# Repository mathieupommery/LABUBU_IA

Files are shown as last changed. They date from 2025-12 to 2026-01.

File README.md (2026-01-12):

# LABUBU IA

<p align="center">
  
</p>

## Hardware

###  Specs
- ESP32-S3
- MEMS Micro ICS-43434
- Amplifier Max 98357
- Built-in LTC4065 lipo charger 
- Built-in 1s lipo and micro sd card
- WIFI/BLE antenna connector
- Push button for application purpose
- connector for external on/off switch, external USB, external speaker and adressable led.

###  PCB
- 4 layers under 900mm2

### Some view 

<p align="center">
  
  
</p>

### 3D pcb case 
<p align="center">
  
  
</p>

##  Software

### Audio_Player 
- Scan button at startup: if pressed goes into msc mode and expose sd card on usb to add new song (sd in spi mode too extremely slow)
- After that scan all the .wav in the memory
- then if you short press : toggle the play state of the current song
- if you long press : play the next song in alphabetical order.

### IA_assistant

-in progress 

## Result 

Picture of the pcb ( cable on top are soldered because i had not the jst ghs 8pin in stock )

<p align="center">
  
  
</p>

View of the pcb with the 1s 150mah lipo battery connected
<p align="center">
  
</p>

View of the External power switch (on one side battery is disconnected from ldo and usb is connected to ldo and on other side usb is disconnected from ldo and battery is connected ) 
and view of the usb port both are hidden in the labubu's feet.

<p align="center">
  
  
</p>

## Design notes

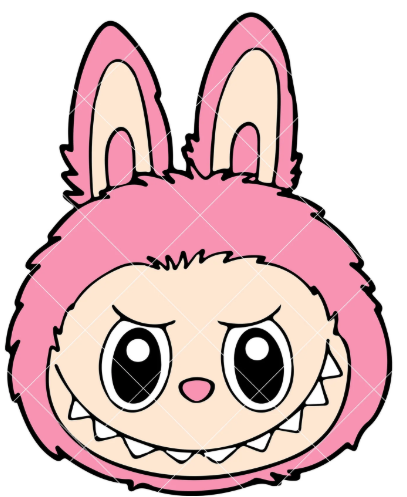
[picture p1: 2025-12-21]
DOCS/labubu.png

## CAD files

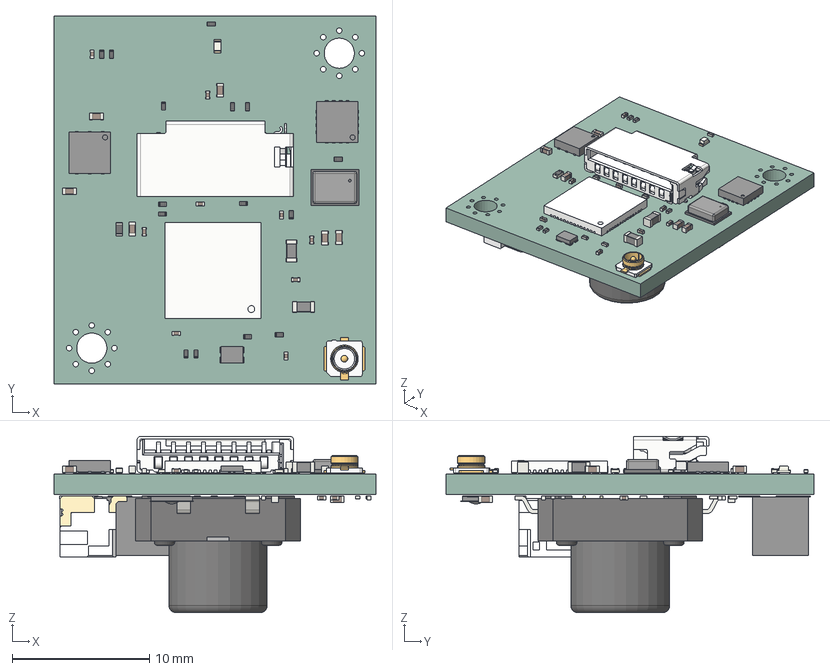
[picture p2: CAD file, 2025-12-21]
HARDWARE/3D/labubupcb.step
23.4 x 26.8 x 12.8 mm
R_0201_0603Metric x 20
C_0402_1005Metric x 9
C_0201_0603Metric x 13
L_0603_1608Metric x 2
ThermalPin
PinsArrayLR
PinsArrayTB
R_0402_1005Metric
LED_0402_1005Metric
Pins
InvenSense_ICS-43434-6_3.5x2.65mm
636101112001_Contact
636101112001_Ground
636101112001_Housing
ThermalPin_1
PinsArrayLR_1
labubupcb 1.41.1
ThermalPin_2
PinsArrayLR_2
SM04B-GHS-TB_LF__SN_
KXT341LHS
SW_Push_1P1T_NO_CK_PTS125Sx85SMTR
Pins_1
PCB_PAPI_PCB

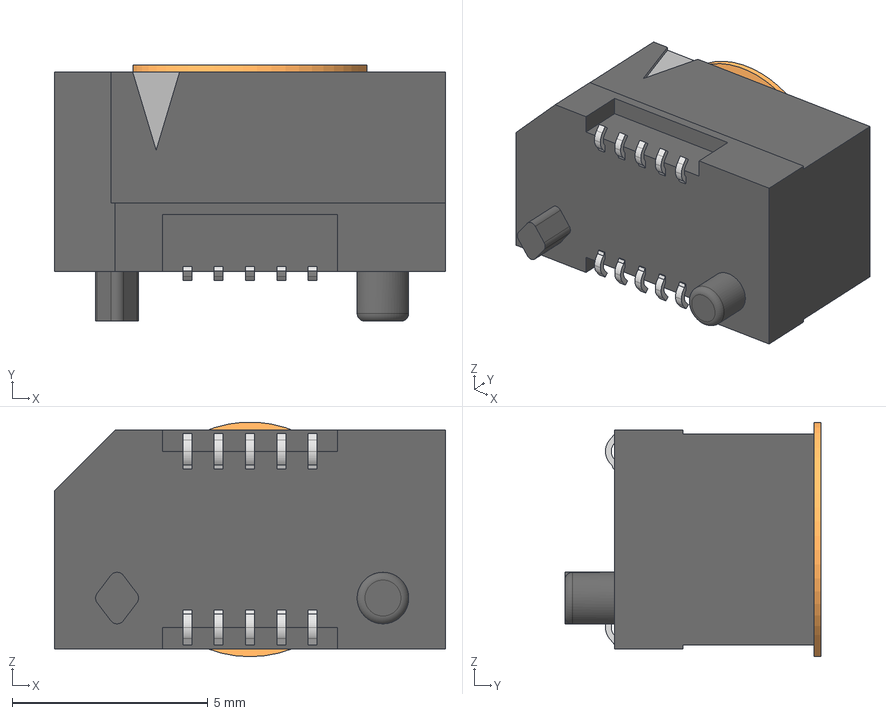
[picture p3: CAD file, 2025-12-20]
HARDWARE/PCB/LIB_KIKAD/ERF8-005/ERF8-005-05.0-L-DV-K-TR.stp
10.0 x 6.56 x 5.99 mm
ERF8-005-05.0-DV-KTR
ERF8-C-211-05.0-005PN
ERF8-C-211-05.0-0052PN
ERF8-005-05.0-DVPFP

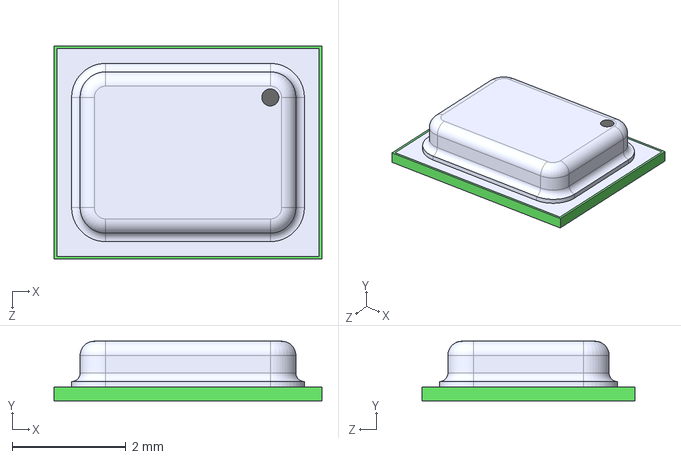
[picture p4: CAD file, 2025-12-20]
HARDWARE/PCB/LIB_KIKAD/INMP441/INMP441ACEZ-R7.step
4.72 x 1.05 x 3.76 mm

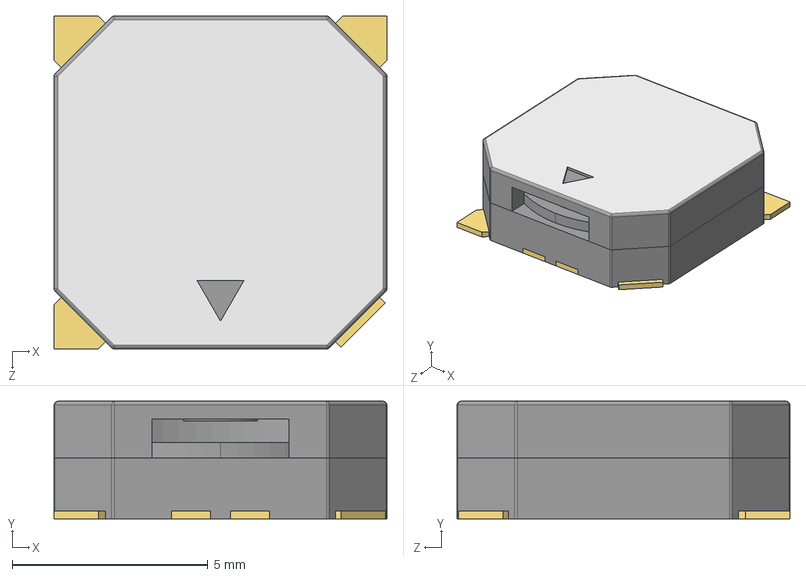
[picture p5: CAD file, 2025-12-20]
HARDWARE/PCB/LIB_KIKAD/libloader/CMT-8503-90-SMT-TR.stp
8.50 x 3.00 x 8.50 mm

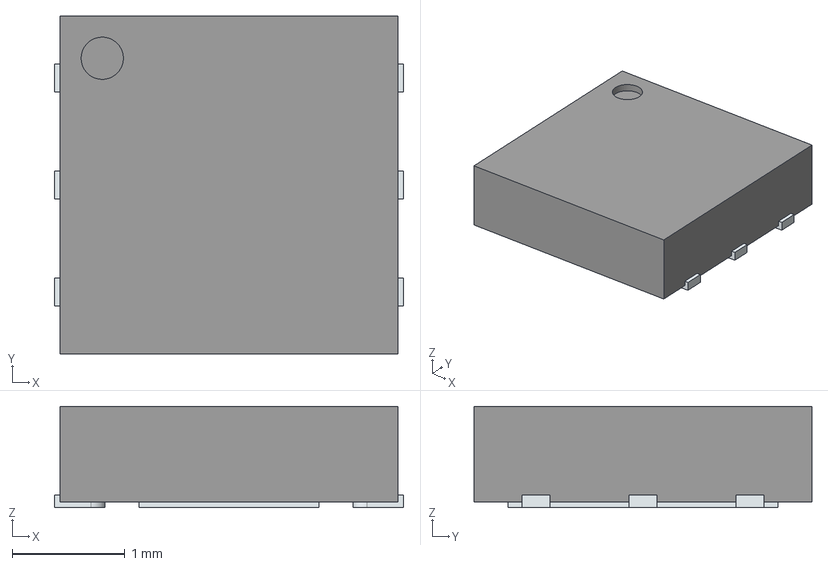
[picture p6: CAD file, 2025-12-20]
HARDWARE/PCB/LIB_KIKAD/libloader/LDO40LPU33RY.stp
3.10 x 3.00 x 0.9 mm
ThermalPin
PinsArrayLR

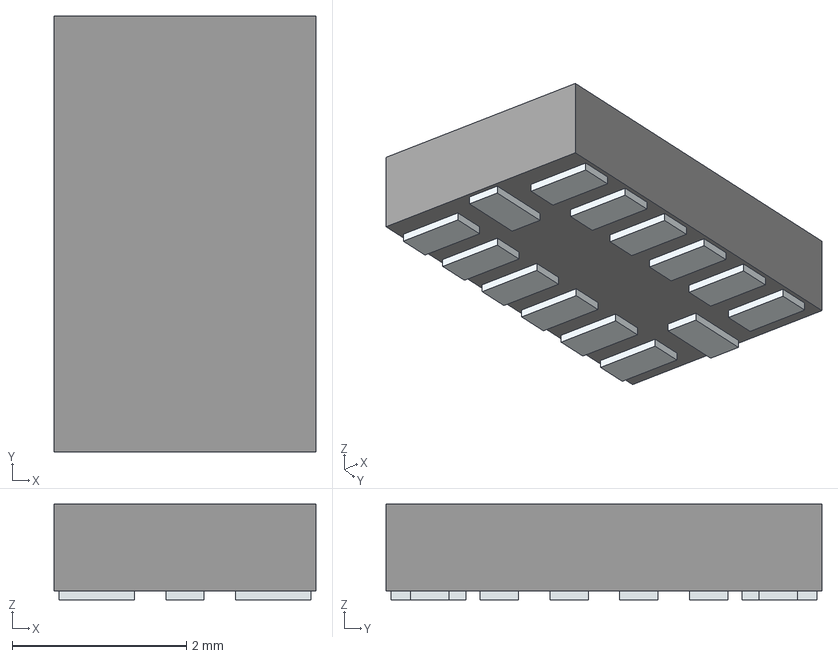
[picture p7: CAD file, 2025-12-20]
HARDWARE/PCB/LIB_KIKAD/libloader/ADXL343BCCZ-RL.stp
3.00 x 5.00 x 1.10 mm
Pins

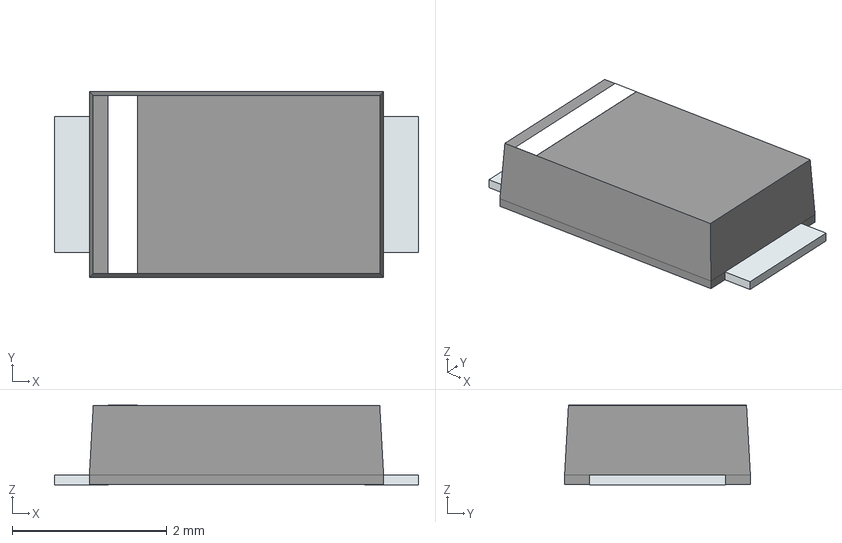
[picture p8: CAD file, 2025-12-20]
HARDWARE/PCB/LIB_KIKAD/libloader/STPS5H100AF.stp
4.70 x 2.40 x 1.03 mm
PinKIdent
PinK
PinA

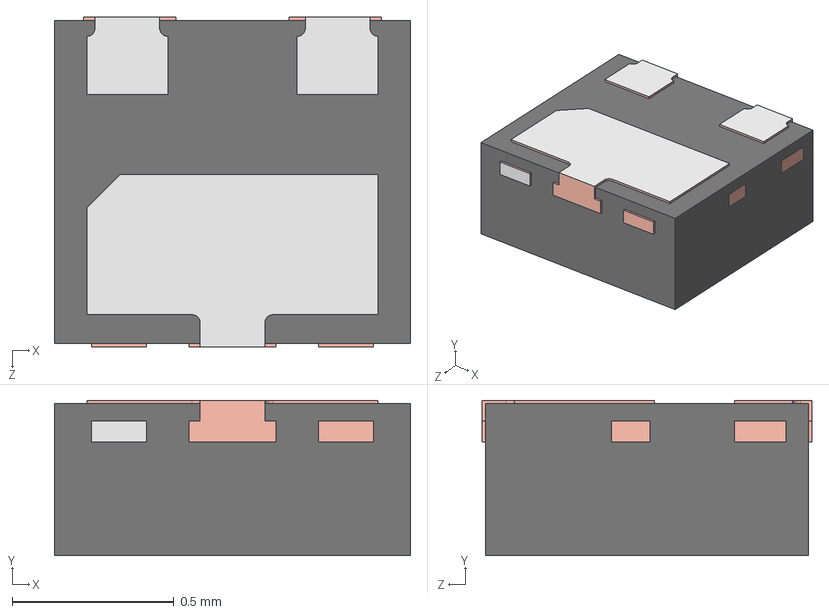
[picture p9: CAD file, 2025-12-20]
HARDWARE/PCB/LIB_KIKAD/libloader/2N7002KQBZ.stp
1.10 x 0.48 x 1.02 mm
SOT8015 LF
SOT8015 Body

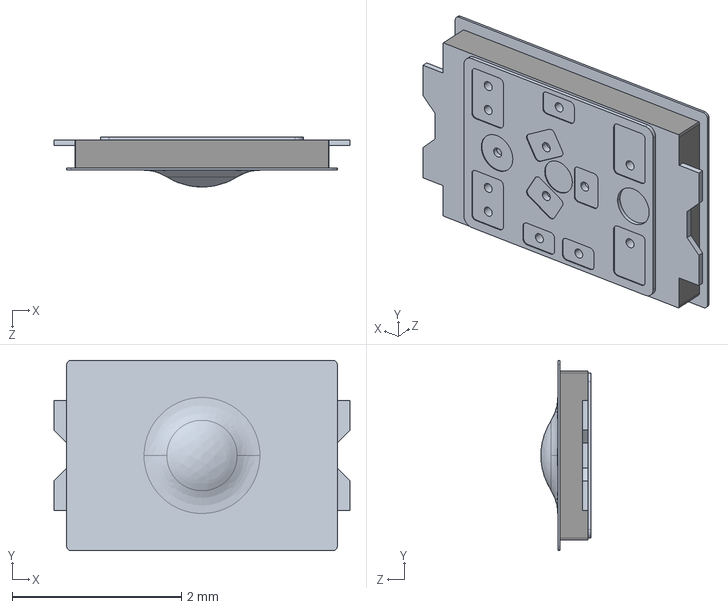
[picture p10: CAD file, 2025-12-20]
HARDWARE/PCB/LIB_KIKAD/libloader/KXT341LHS.stp
3.50 x 2.25 x 0.595 mm

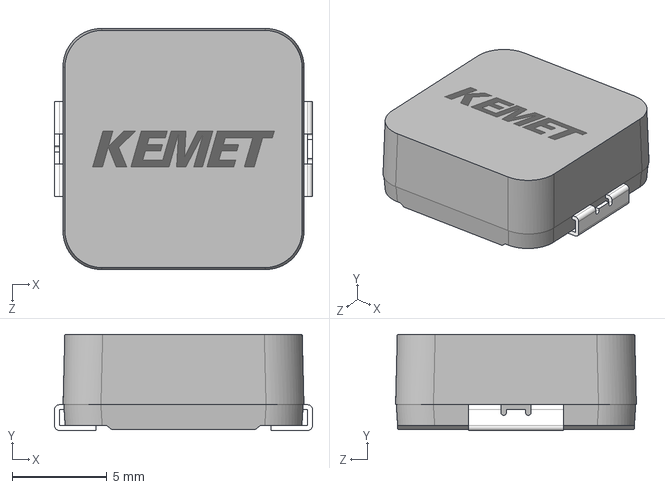
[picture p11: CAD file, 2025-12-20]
HARDWARE/PCB/LIB_KIKAD/libloader/MPX1D1250L4R7.stp
13.6 x 5.06 x 12.7 mm

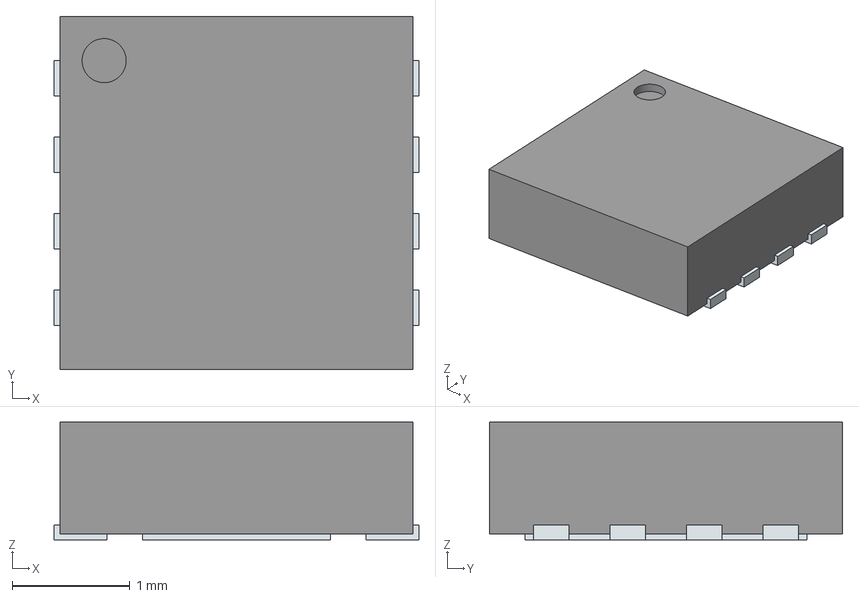
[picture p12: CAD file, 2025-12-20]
HARDWARE/PCB/LIB_KIKAD/libloader/NCV7342MW3R2G.stp
3.10 x 3.00 x 1.00 mm
ThermalPin
PinsArrayLR

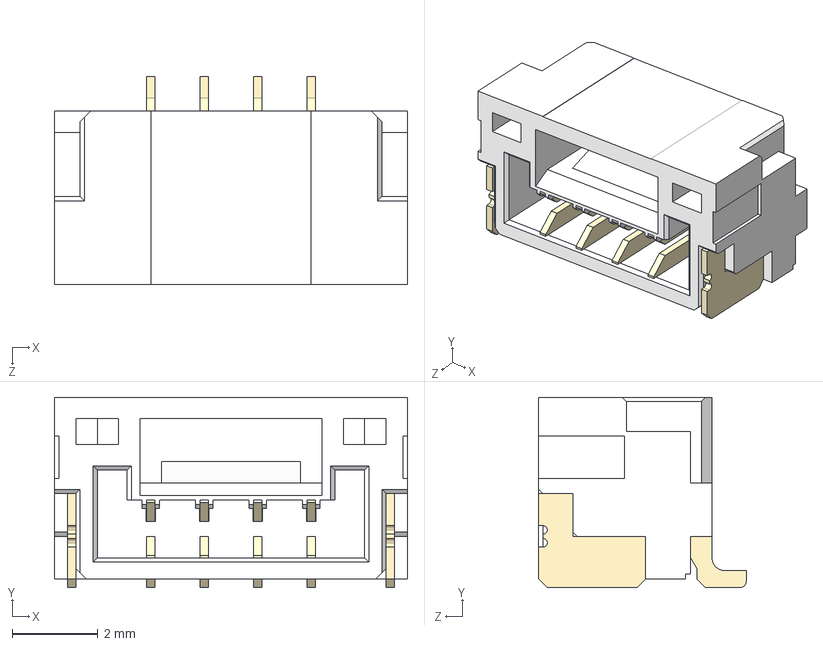
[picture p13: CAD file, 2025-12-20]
HARDWARE/PCB/LIB_KIKAD/libloader/SM04B-GHS-TB_LF__SN_.stp
8.25 x 4.45 x 4.85 mm

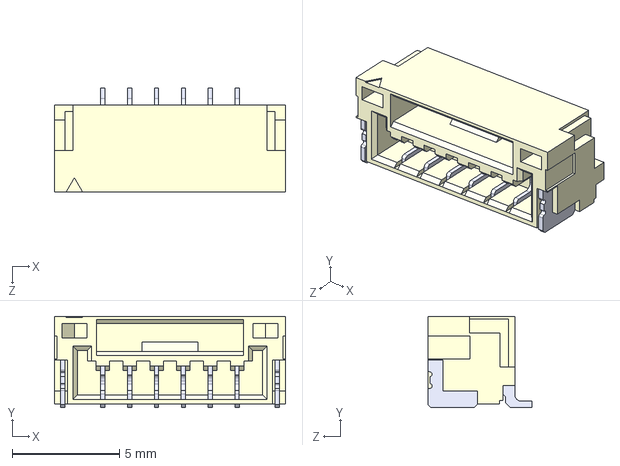
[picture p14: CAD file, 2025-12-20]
HARDWARE/PCB/LIB_KIKAD/libloader/SM06B-GHS-TB_LF__SN_.stp
10.8 x 4.25 x 4.85 mm

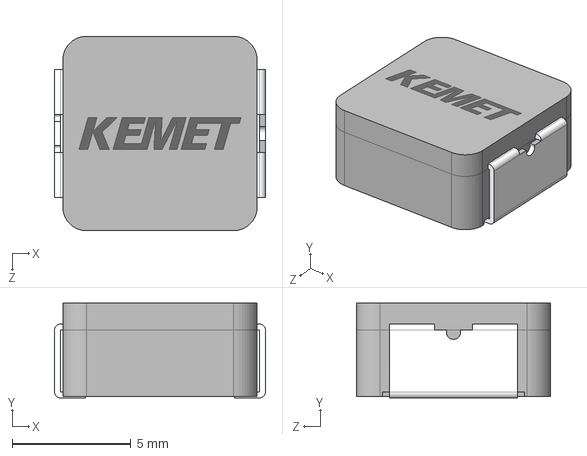
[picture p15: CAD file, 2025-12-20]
HARDWARE/PCB/LIB_KIKAD/libloader/MPX1D0840L470.stp
8.90 x 4.00 x 8.20 mm

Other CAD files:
HARDWARE/PCB/LIB_KIKAD/libloader/SM10B-SRSS-TB_LF__SN_.stp
HARDWARE/PCB/LIB_KIKAD/libloader/TLE5012BE3005XUMA1.stp
HARDWARE/PCB/LIB_KIKAD/libloader/ESP32-S3FH4R2.stp
HARDWARE/PCB/LIB_KIKAD/libloader/XT30PW-M.stp
HARDWARE/PCB/LIB_KIKAD/libloader/1050281001.stp
HARDWARE/PCB/LIB_KIKAD/libloader/3670108.stp
HARDWARE/PCB/LIB_KIKAD/libloader/3670148.stp
HARDWARE/PCB/LIB_KIKAD/libloader/435151014824.stp
HARDWARE/PCB/LIB_KIKAD/libloader/47309-2651.stp
HARDWARE/PCB/LIB_KIKAD/libloader/5871024147F.stp
HARDWARE/PCB/LIB_KIKAD/libloader/636101111001.stp
HARDWARE/PCB/LIB_KIKAD/libloader/687108183722.stp
HARDWARE/PCB/LIB_KIKAD/libloader/7443320470.stp
HARDWARE/PCB/LIB_KIKAD/libloader/74438335033.stp
HARDWARE/PCB/LIB_KIKAD/libloader/74438335220.stp
HARDWARE/PCB/LIB_KIKAD/libloader/74438357100.stp
HARDWARE/PCB/LIB_KIKAD/libloader/74439358100.stp
HARDWARE/PCB/LIB_KIKAD/libloader/82400274.stp
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

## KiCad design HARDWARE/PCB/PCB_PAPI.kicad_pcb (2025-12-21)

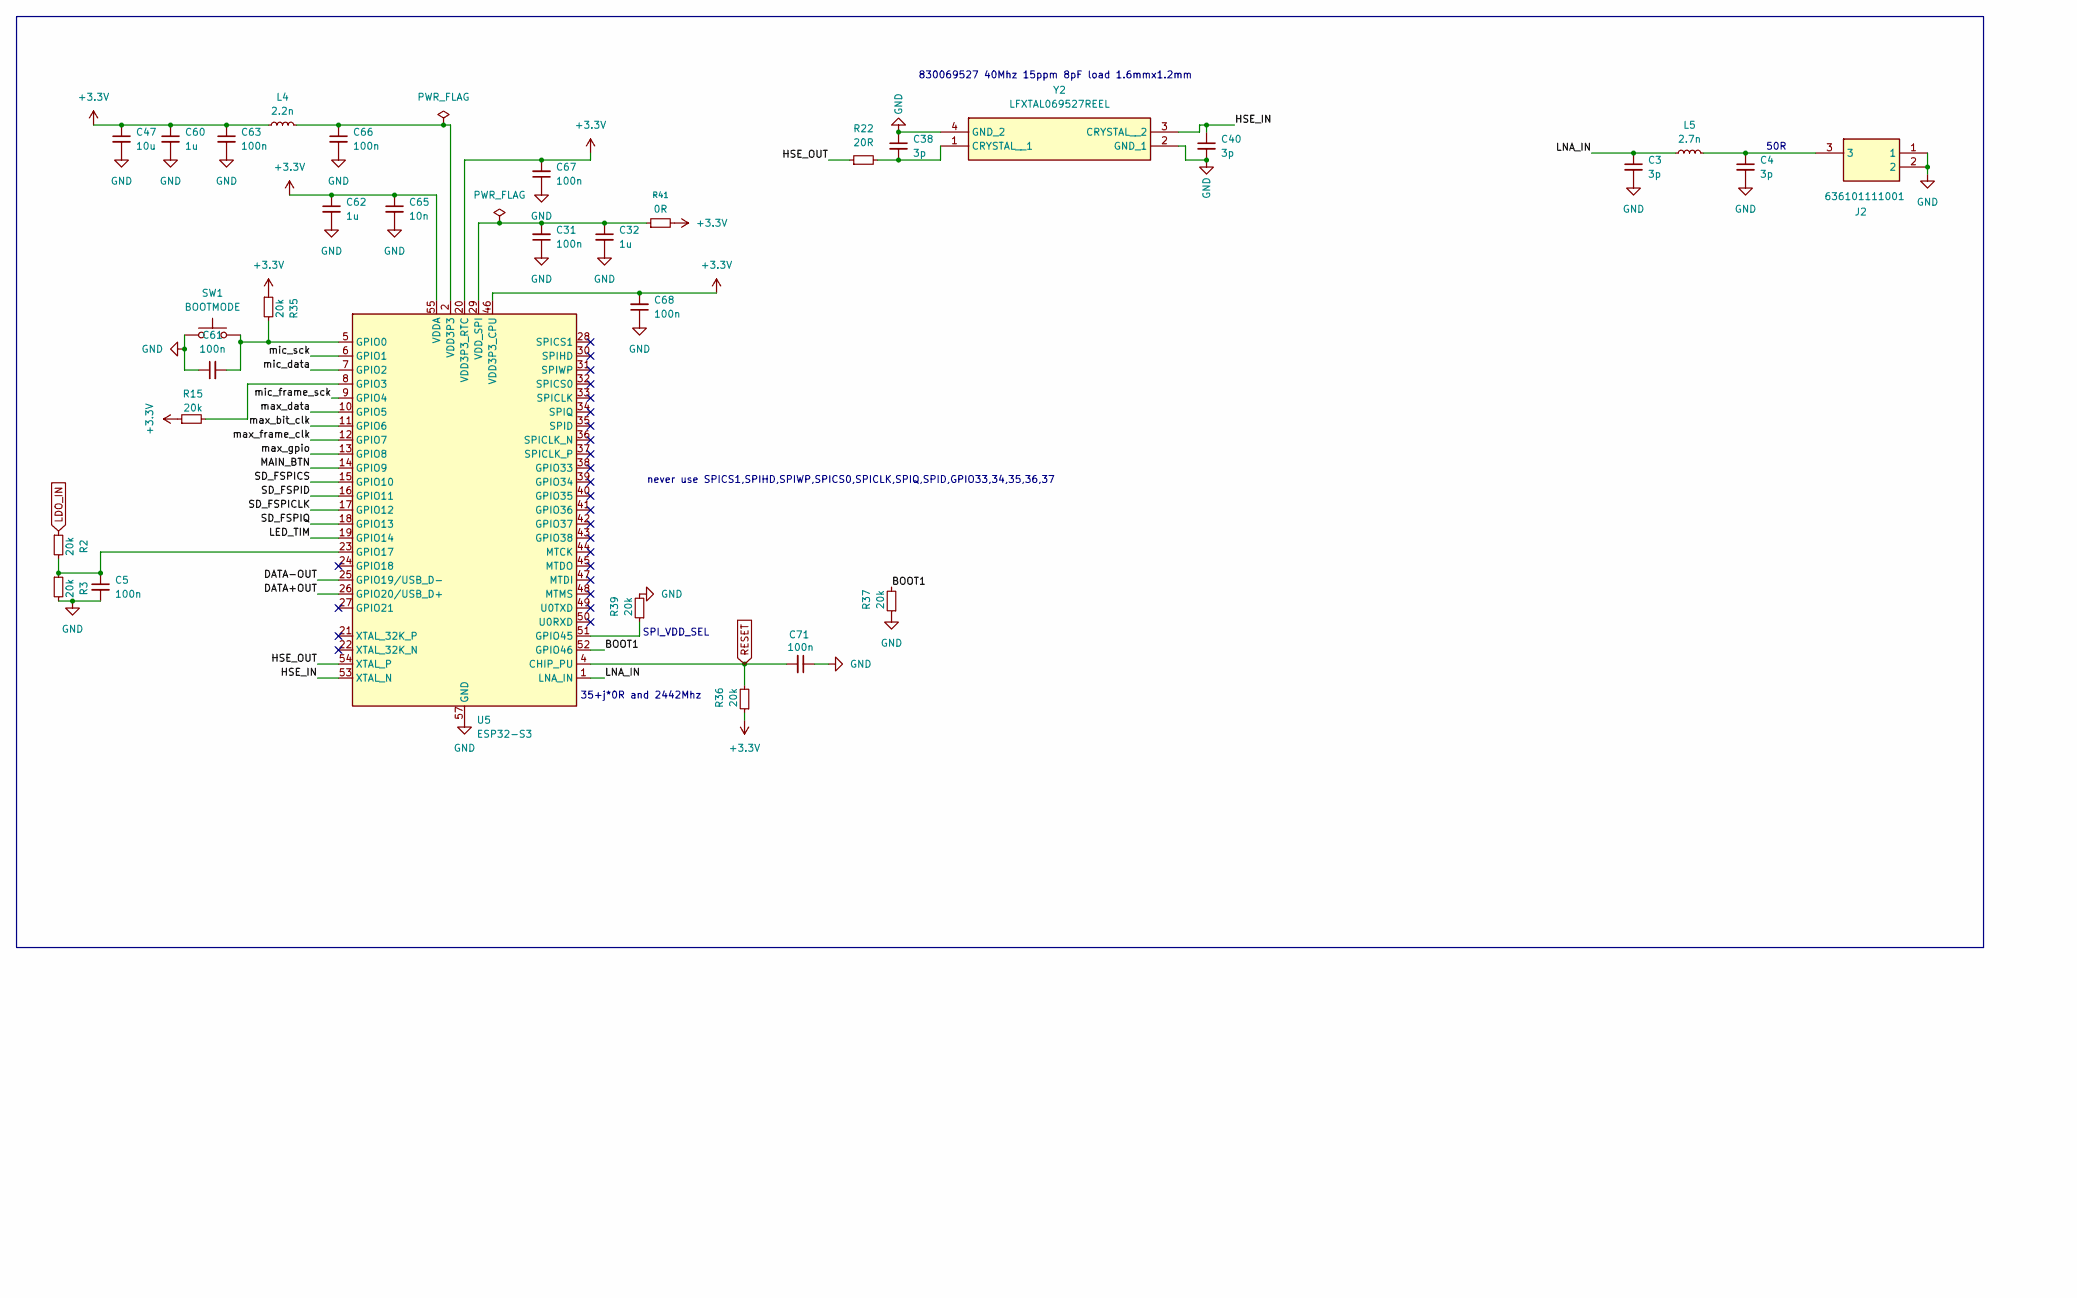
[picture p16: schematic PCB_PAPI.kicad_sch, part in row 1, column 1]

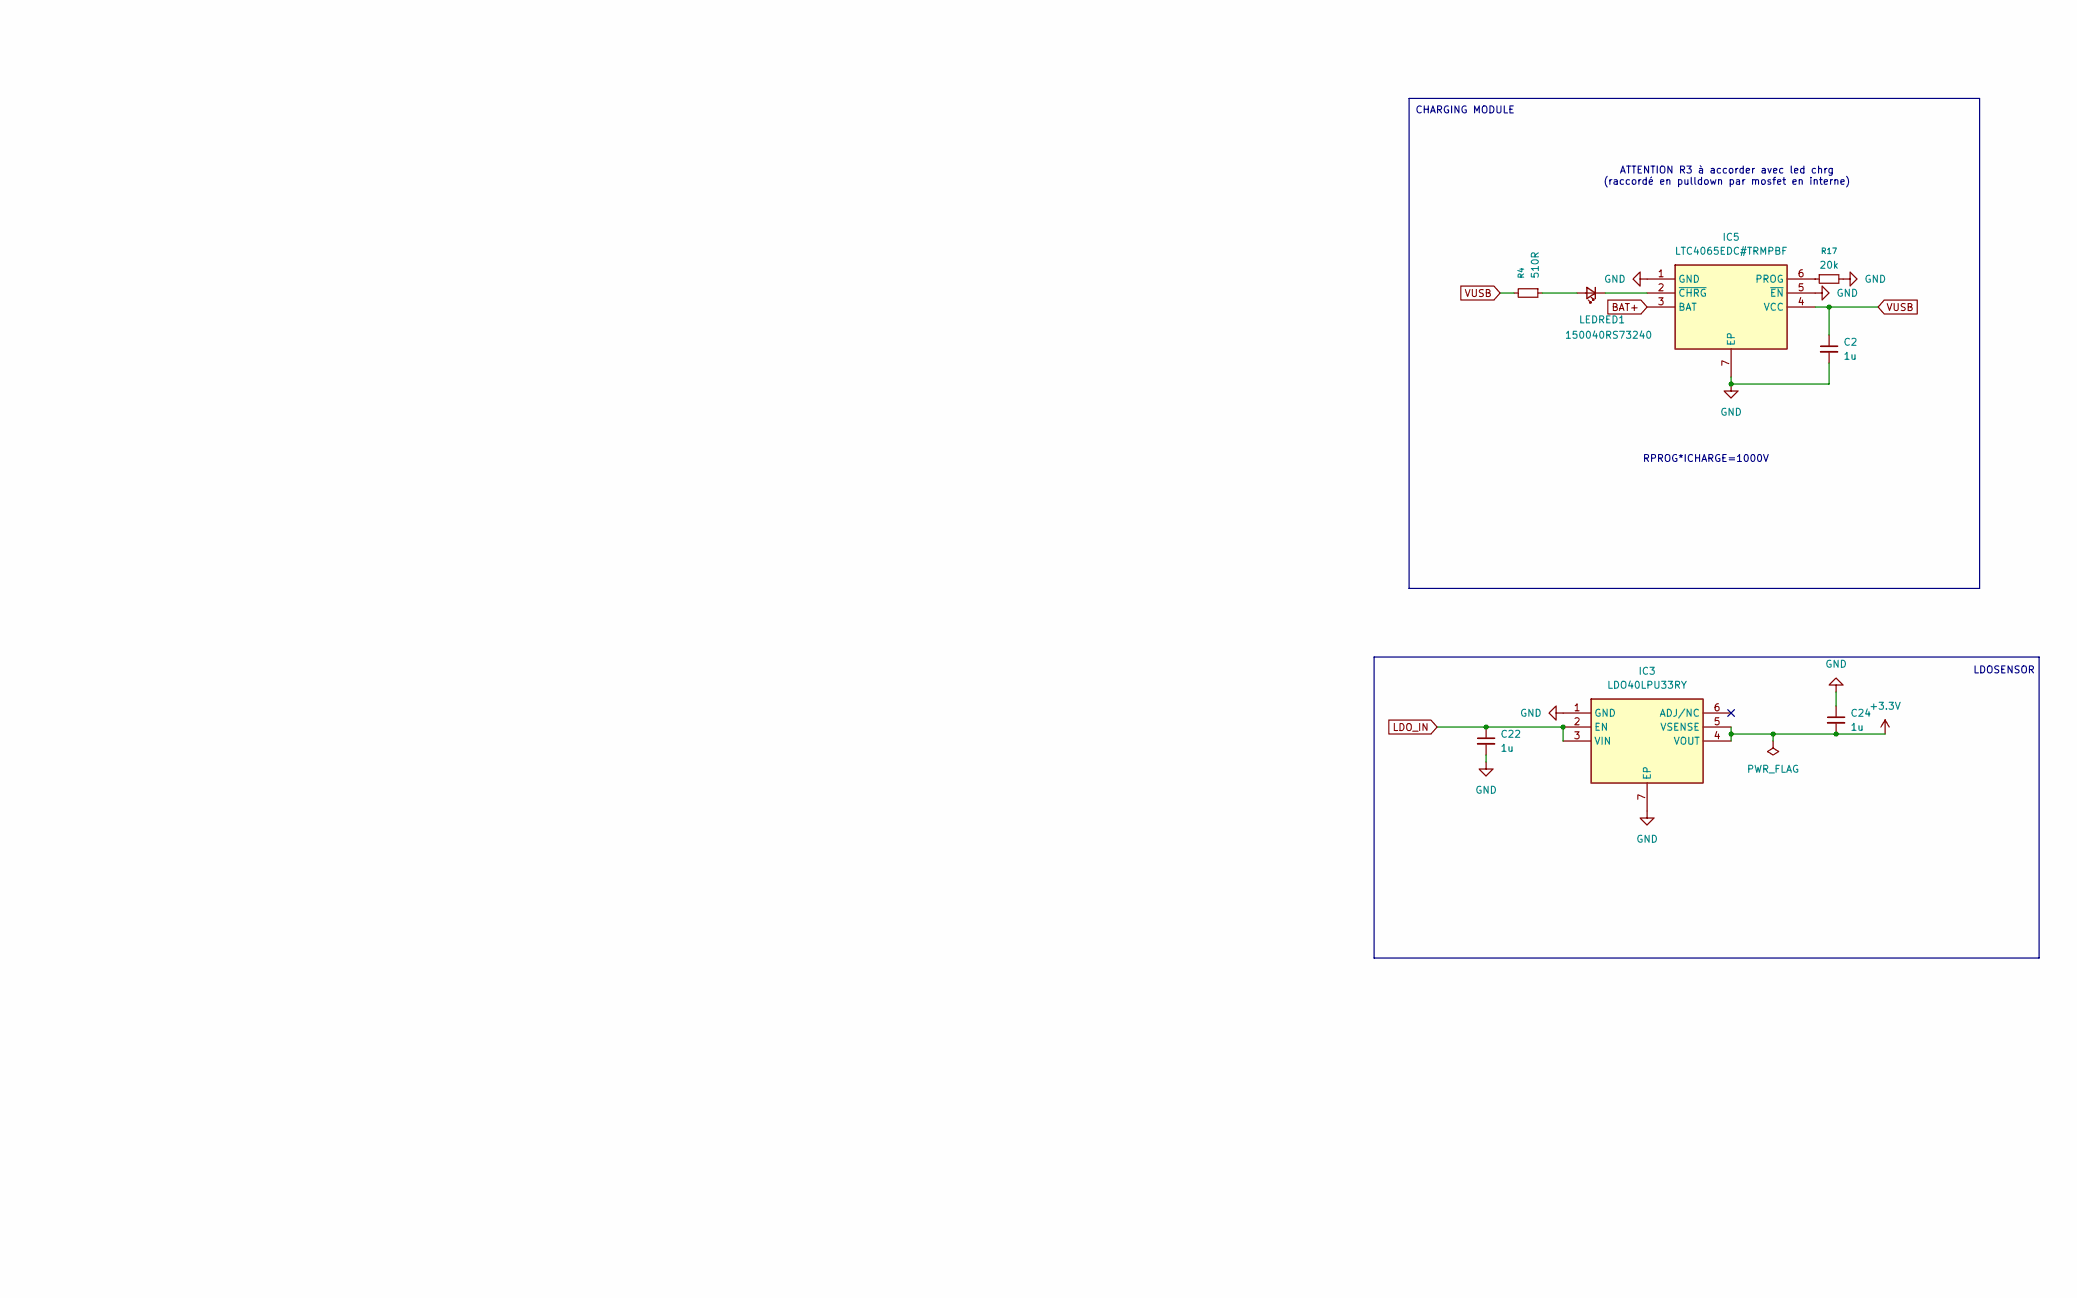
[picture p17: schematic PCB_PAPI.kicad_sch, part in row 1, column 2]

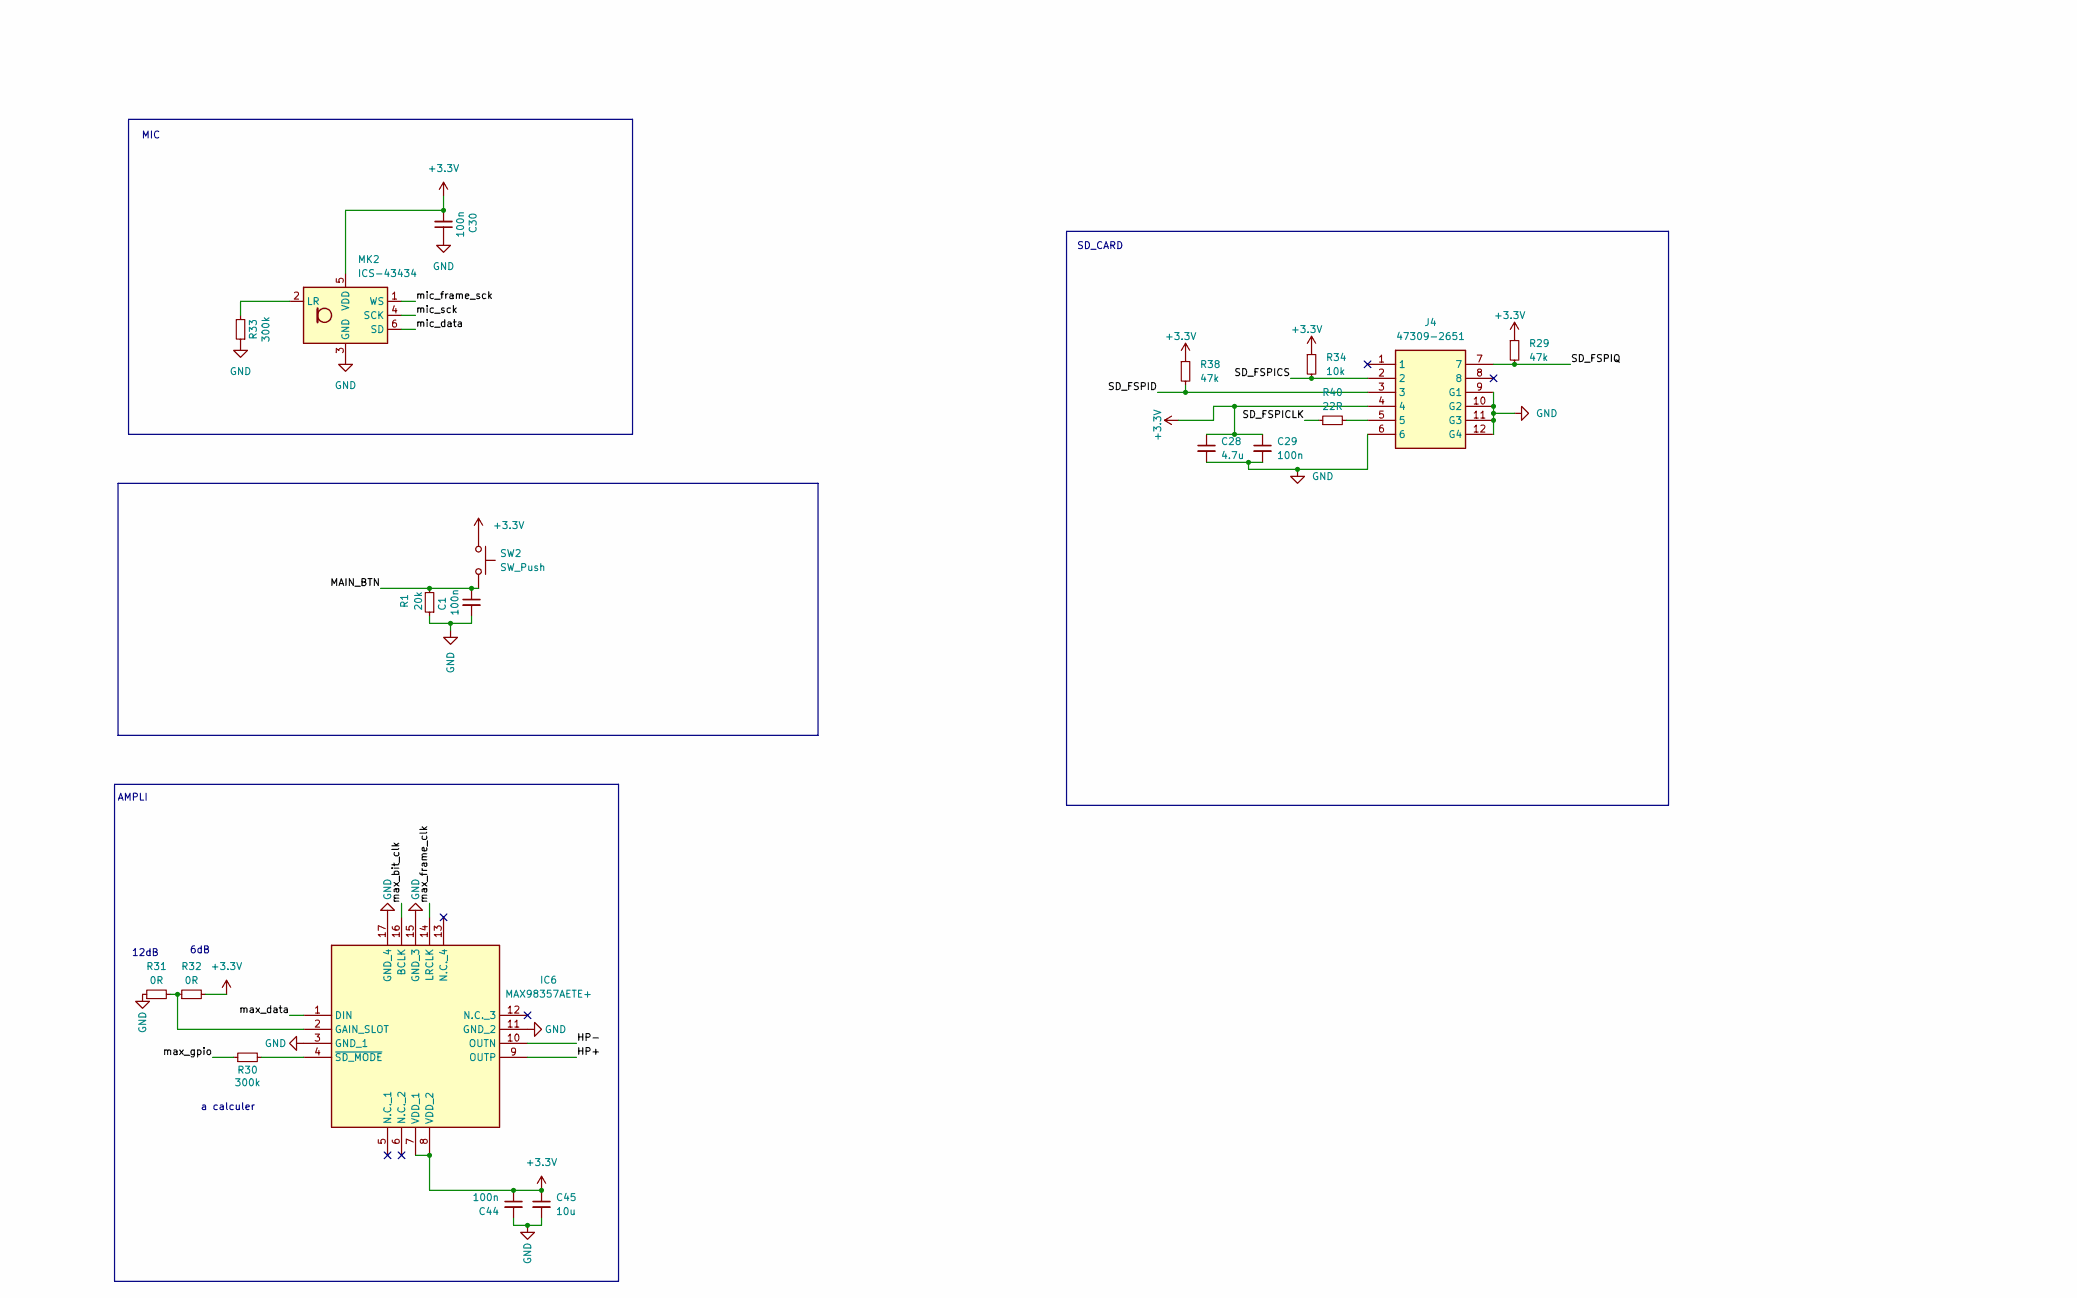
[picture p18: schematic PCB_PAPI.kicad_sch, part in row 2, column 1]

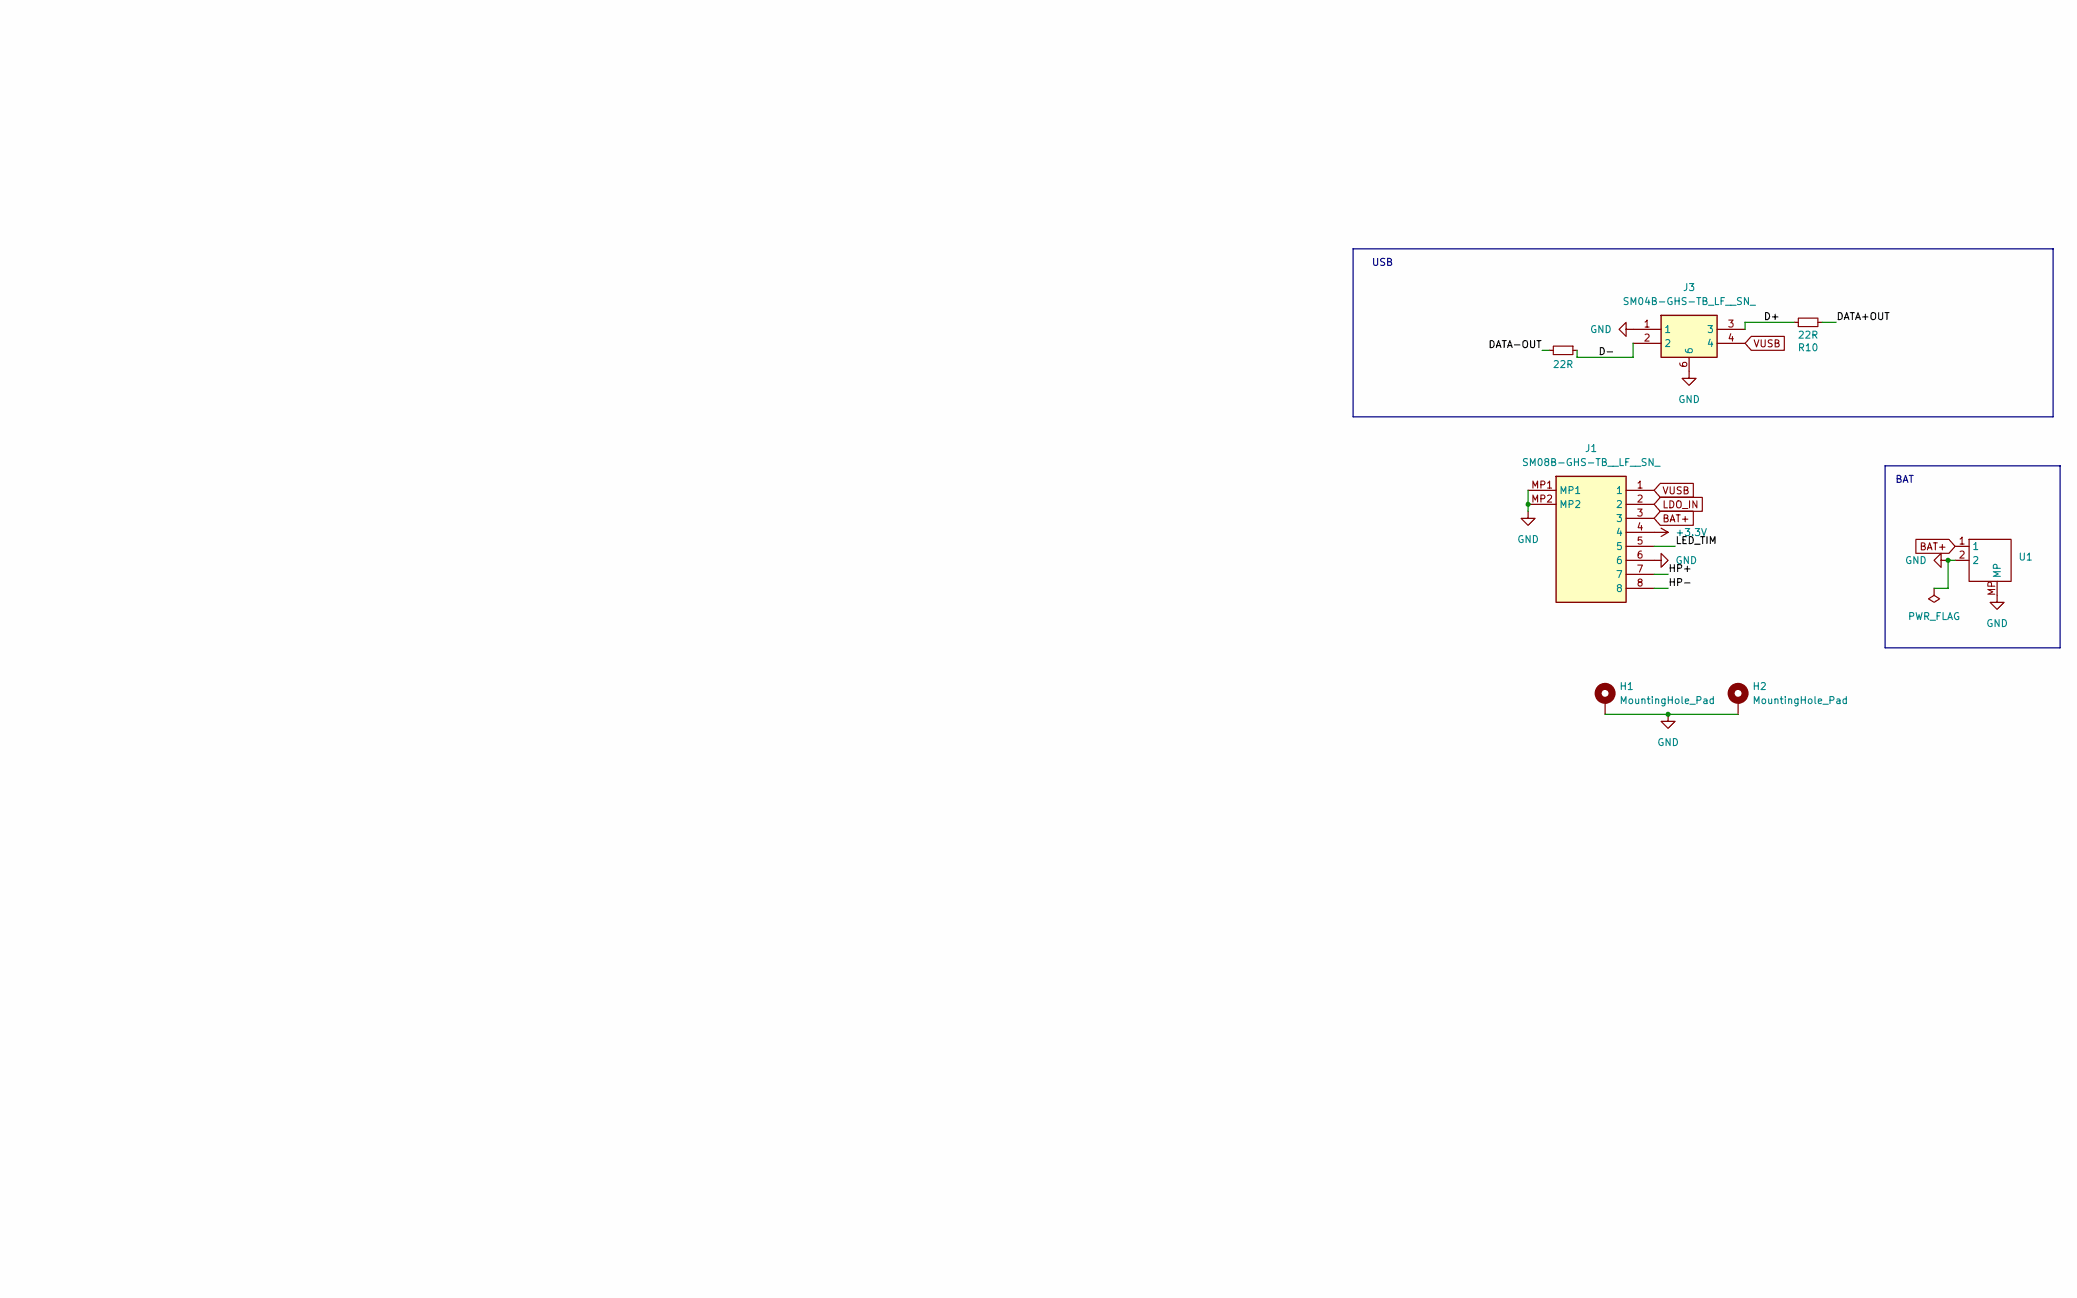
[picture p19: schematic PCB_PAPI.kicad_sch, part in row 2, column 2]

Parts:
C1, C5, C30, C31, C61, C63, C66, C67, C68, C71: 100n; C_0201_0603Metric_Pad0.64x0.40mm_HandSolder
C2: 1u; C_0402_1005Metric
C3, C4, C38, C40: 3p; C_0201_custom
C22, C24: 1u; C_0402_1005Metric; Manufacturer_Part_Number 885012105012; Mouser Part Number 710-885012105012
C28: 4.7u; C_0402_1005Metric_Pad0.74x0.62mm_HandSolder
C29, C44: 100n; C_0201_0603Metric
C32, C60, C62: 1u; C_0402_1005Metric_Pad0.74x0.62mm_HandSolder
C45: 10u; C_0402_1005Metric; Manufacturer_Part_Number 885012105008; Mouser Part Number 710-885012105008
C47: 10u; C_0402_1005Metric_Pad0.74x0.62mm_HandSolder
C65: 10n; C_0201_0603Metric_Pad0.64x0.40mm_HandSolder
H1, H2: MountingHole_Pad; MountingHole_2.2mm_M2_Pad_Via
IC3: LDO40LPU33RY; SON95P300X300X90-7N-D; Manufacturer_Part_Number LDO40LPU33RY; Mouser Part Number 511-LDO40LPU33RY
IC5: LTC4065EDC#TRMPBF; SON50P200X200X80-7N-D; Manufacturer_Part_Number LTC4065EDC#TRMPBF; Mouser Part Number 584-LTC4065EDCTRMPBF
IC6: MAX98357AETE+; QFN50P300X300X80-17N; Manufacturer_Part_Number MAX98357AETE+; Mouser Part Number 700-MAX98357AETE+
J1: SM08B-GHS-TB__LF__SN_; SM08BGHSTBLFSN; Manufacturer_Part_Number SM08B-GHS-TB (LF)(SN)
J2: 636101111001; Mouser Part Number 710-636101111001
J3: SM04B-GHS-TB_LF__SN_; SM04B-GHS-TB; Manufacturer_Part_Number SM04B-GHS-TB(LF)(SN); Mouser Part Number N/A
J4: 47309-2651; 473092651; Manufacturer_Part_Number 47309-2651
L4: 2.2n; L_0603_1608Metric
L5: 2.7n; L_0603_1608Metric
LEDRED1: 150040RS73240; LED_0402_1005Metric; Manufacturer_Part_Number 150040GS73240; Mouser Part Number 710-150040GS73240
MK2: ICS-43434; InvenSense_ICS-43434-6_3.5x2.65mm
R1, R2, R3, R15, R35, R36, R37, R39: 20k; R_0201_0603Metric_Pad0.64x0.40mm_HandSolder
R4: 510R; R_0201_0603Metric_Pad0.64x0.40mm_HandSolder; Mouser Part Number 603-RC0201JR-07510RL
R9, R10: 22R; R_0201_0603Metric; Manufacturer_Part_Number ERJ-1GNF22R0C; Mouser Part Number 667-ERJ-1GNF22R0C
R17: 20k; R_0201_0603Metric_Pad0.64x0.40mm_HandSolder; Mouser Part Number 603-AC0201FR-0720KL
R22: 20R; R_0201_0603Metric
R29, R38: 47k; R_0201_0603Metric
R30, R33: 300k; R_0201_0603Metric; Manufacturer_Part_Number ERJ-1GNF1000C; Mouser Part Number 667-ERJ-1GNF1000C
R31: 0R; R_0201_custom; Manufacturer_Part_Number ERJ-1GNF1000C; Mouser Part Number 667-ERJ-1GNF1000C
R32: 0R; R_0201_0603Metric; Manufacturer_Part_Number ERJ-1GNF1000C; Mouser Part Number 667-ERJ-1GNF1000C
R34: 10k; R_0201_0603Metric
R40: 22R; R_0201_0603Metric
R41: 0R; R_0402_1005Metric_Pad0.72x0.64mm_HandSolder
SW1: BOOTMODE; KXT341LHS
SW2: SW_Push; SW_Push_1P1T_NO_CK_PTS125Sx85SMTR
U1: JST_SH_BM02B-SRSS-TB_1x02-1MP_P1.00mm_Vertical; Mouser Part Number 306-BM02BSRSSTBLFSNP
U5: ESP32-S3; QFN-56-1EP_7x7mm_P0.4mm_EP4x4mm
Y2: LFXTAL069527REEL; Manufacturer_Part_Number LFXTAL069527REEL

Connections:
+3.3V: C24.2, C28.1, C29.1, C30.2, C44.1, C45.1, C47.1, C60.1, C62.1, C63.1, C65.1, C67.2, C68.2, IC3.4 (VOUT), IC3.5 (VSENSE), IC6.7 (VDD_1), IC6.8 (VDD_2), J1.4, J4.4, L4.1, MK2.5 (VDD), R15.1, R29.1, R32.2, R34.1, R35.1, R36.1, R38.1, R41.2, SW2.1, U5.20 (VDD3P3_RTC), U5.46 (VDD3P3_CPU), U5.55 (VDDA), U5.56 (VDDA)
/BOOT1: R37.2, U5.52 (GPIO46)
/D+: J3.3, R10.1
/D-: J3.2, R9.1
/DATA+OUT: R10.2, U5.26 (GPIO20/USB_D+)
/DATA-OUT: R9.2, U5.25 (GPIO19/USB_D-)
/HP+: IC6.9 (OUTP), J1.7
/HP-: IC6.10 (OUTN), J1.8
/HSE_IN: C40.1, U5.53 (XTAL_N), Y2.3 (CRYSTAL__2)
/HSE_OUT: R22.1, U5.54 (XTAL_P)
/LED_TIM: J1.5, U5.19 (GPIO14)
/LNA_IN: C3.1, L5.1, U5.1 (LNA_IN)
/MAIN_BTN: C1.1, R1.2, SW2.2, U5.14 (GPIO9)
/SD_FSPICLK: R40.1, U5.17 (GPIO12)
/SD_FSPICS: J4.2, R34.2, U5.15 (GPIO10)
/SD_FSPID: J4.3, R38.2, U5.16 (GPIO11)
/SD_FSPIQ: J4.7, R29.2, U5.18 (GPIO13)
/max_bit_clk: IC6.16 (BCLK), U5.11 (GPIO6)
/max_data: IC6.1 (DIN), U5.10 (GPIO5)
/max_frame_clk: IC6.14 (LRCLK), U5.12 (GPIO7)
/max_gpio: R30.1, U5.13 (GPIO8)
/mic_data: MK2.6 (SD), U5.7 (GPIO2)
/mic_frame_sck: MK2.1 (WS), U5.9 (GPIO4)
/mic_sck: MK2.4 (SCK), U5.6 (GPIO1)
BAT+: IC5.3 (BAT), J1.3, U1.1
GND: C1.2, C2.2, C3.2, C4.2, C5.2, C22.2, C24.1, C28.2, C29.2, C30.1, C31.1, C32.2, C38.1, C40.2, C44.2, C45.2, C47.2, C60.2, C61.1, C62.2, C63.2, C65.2, C66.2, C67.1, C68.1, C71.1, H1.1, H2.1, IC3.1 (GND), IC3.7 (EP), IC5.1 (GND), IC5.5 (~EN), IC5.7 (EP), IC6.3 (GND_1), IC6.11 (GND_2), IC6.15 (GND_3), IC6.17 (GND_4), J1.6, J1.MP1, J1.MP2, J2.1, J2.2, J3.1, J3.5, J3.6, J4.6, J4.9 (G1), J4.10 (G2), J4.11 (G3), J4.12 (G4), MK2.3 (GND), R1.1, R3.2, R17.2, R31.1, R33.1, R37.1, R39.2, SW1.1, U1.2, U1.MP, U5.57 (GND), Y2.2 (GND_1), Y2.4 (GND_2)
LDO_IN: C22.1, IC3.2 (EN), IC3.3 (VIN), J1.2, R2.1
unnamed: C4.1, J2.3, L5.2
unnamed: C66.1, L4.2, U5.2 (VDD3P3), U5.3 (VDD3P3)
unnamed: IC5.6 (PROG), R17.1
unnamed: IC5.2 (~CHRG), LEDRED1.1 (K)
unnamed: IC6.2 (GAIN_SLOT), R31.2, R32.1
unnamed: IC6.4 (~SD_MODE), R30.2
unnamed: J4.5, R40.2
unnamed: LEDRED1.2 (A), R4.1
unnamed: MK2.2 (LR), R33.2
unnamed: C61.2, R35.2, SW1.2, U5.5 (GPIO0)
unnamed: R15.2, U5.8 (GPIO3)
unnamed: C5.1, R2.2, R3.1, U5.23 (GPIO17)
unnamed: R39.1, U5.51 (GPIO45)
unnamed: C31.2, C32.1, R41.1, U5.29 (VDD_SPI)
unnamed: C38.2, R22.2, Y2.1 (CRYSTAL__1)
RESET: C71.2, R36.2, U5.4 (CHIP_PU)
VUSB: C2.1, IC5.4 (VCC), J1.1, J3.4, R4.2

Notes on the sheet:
MIC
SPI_VDD_SEL
12dB
35+j*0R and 2442Mhz
SD_CARD
50R
a calculer
BAT
RPROG*ICHARGE=1000V
never use SPICS1,SPIHD,SPIWP,SPICS0,SPICLK,SPIQ,SPID,GPIO33,34,35,36,37
AMPLI
CHARGING MODULE
830069527 40Mhz 15ppm 8pF load 1.6mmx1.2mm
ATTENTION R3 à accorder avec led chrg (raccordé en pulldown par mosfet en interne)
6dB
USB
LDOSENSOR

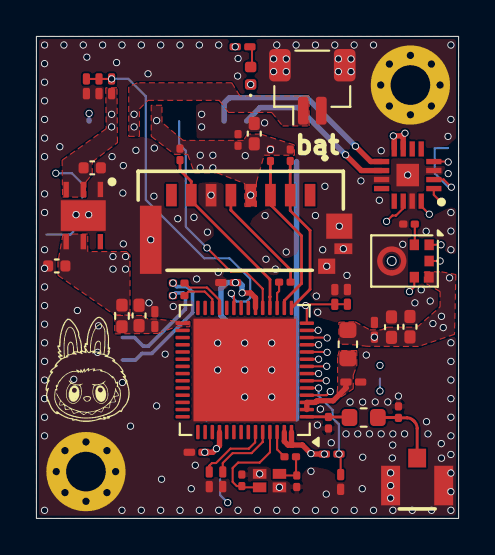
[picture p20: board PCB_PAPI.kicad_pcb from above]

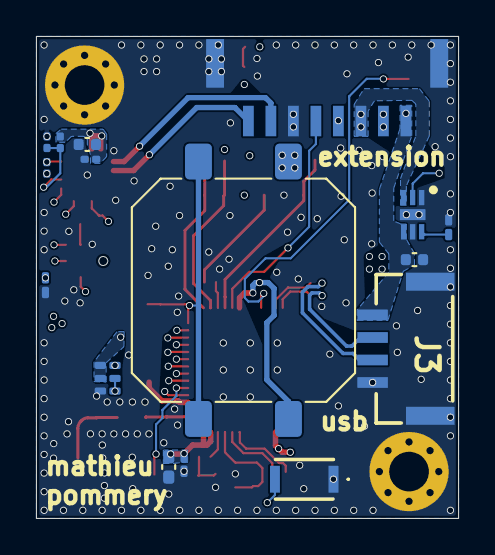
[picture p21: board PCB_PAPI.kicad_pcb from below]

Board: 4 copper layers, 23.4 x 26.8 mm, 66 parts (18 on the bottom side), 44 nets.

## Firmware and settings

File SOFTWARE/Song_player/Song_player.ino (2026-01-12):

#include <Arduino.h>
#include <SPI.h>
#include <SD.h>
#include <USBMSC.h>
#include <USB.h>
#include "driver/i2s.h"
#include "wav.h"


#define BTN_PIN 9      // change si besoin

#define LONG_PRESS_MS 400

static const uint16_t SECTOR_SIZE = 512;

USBMSC usbMsc;
SPIClass sdSPI(FSPI);   // bus SPI pour la SD sur ESP32-S3 (FSPI)

// =======================
// Paramètres WAV & volume
// =======================
std::vector<String> wavList;

// Volume logiciel (0.0 = muet, 1.0 = plein volume)
float g_volume = 1.0f;   // tu peux régler ça



// =======================
// Prototypes
// =======================
void playbackTask(void *parameter);
void buttonTask(void *parameter);




void setupAudioMode() {
  // Init SPI pour la carte SD
  Serial.println("Init SPI SD...");
  sdSPI.begin(SD_SCK_PIN, SD_MISO_PIN, SD_MOSI_PIN, SD_CS_PIN);

  Serial.print("Init SD...");
  if (!SD.begin(SD_CS_PIN, sdSPI)) {
    Serial.println(" ECHEC !");
    while (true) {
      Serial.println("Erreur SD.begin(). Vérifie SCK/MISO/MOSI/CS.");
      delay(2000);
    }
  }
  
  File root = SD.open("/");
  if (!root || !root.isDirectory()) {
    Serial.println("Impossible d'ouvrir /");
    return;
  }

  File file = root.openNextFile();
  while (file) {
    if (!file.isDirectory()) {
      String name = file.name();
      String lower = name;
      lower.toLowerCase();

      if (lower.endsWith(".wav")) {
        wavList.push_back(name);
      }
    }
    file = root.openNextFile();
  }

  Serial.printf("Trouvé %u fichier(s) WAV :\n", wavList.size());

  for (size_t i = 0; i < wavList.size(); i++) {
    Serial.printf("  [%u] %s\n", i, wavList[i].c_str());
  }
  g_wavCmdQueue = xQueueCreate(4, sizeof(WavCommand));

  xTaskCreatePinnedToCore(playbackTask,"playbackTask",8192,nullptr,2,nullptr,1);
  xTaskCreatePinnedToCore(buttonTask,"buttonTask",2048,nullptr,1,nullptr,1);
}



// ======== CALLBACK LECTURE SECTEURS ========
static int32_t myMscRead(uint32_t lba, uint32_t offset, void *buffer, uint32_t bufsize)
{
  (void)offset;
  uint8_t *buf = (uint8_t *)buffer;
  uint32_t nSectors = bufsize / SECTOR_SIZE;

  for (uint32_t i = 0; i < nSectors; ++i) {
    if (!SD.readRAW(buf + (i * SECTOR_SIZE), lba + i)) {
      return -1;  // erreur de lecture
    }
  }
  return (int32_t)bufsize;
}

// ======== CALLBACK ÉCRITURE SECTEURS ========
static int32_t myMscWrite(uint32_t lba, uint32_t offset, uint8_t *buffer, uint32_t bufsize)
{
  (void)offset;
  uint8_t *buf = (uint8_t *)buffer;
  uint32_t nSectors = bufsize / SECTOR_SIZE;

  for (uint32_t i = 0; i < nSectors; ++i) {
    if (!SD.writeRAW(buf + (i * SECTOR_SIZE), lba + i)) {
      return -1;  // erreur d'écriture
    }
  }
  return (int32_t)bufsize;
}

// ======== CALLBACK START/STOP (éjection) ========
static bool myMscStartStop(uint8_t power_condition, bool start, bool load_eject)
{
  (void)power_condition;
  Serial.printf("MSC StartStop: start=%d eject=%d\n", start, load_eject);
  return true;
}


void setupMassStorageMode() {
  // ---- SD INIT ----
  sdSPI.begin(SD_SCK_PIN, SD_MISO_PIN, SD_MOSI_PIN, SD_CS_PIN);
  if (!SD.begin(SD_CS_PIN, sdSPI)) {
    Serial.println("SD init FAIL");
    while (true) delay(1000);
  }
  

  uint32_t sectorCount = SD.numSectors();   // OK avec le core ESP32

  // ---- Config USB MSC ----
  usbMsc.vendorID("ESP32");
  usbMsc.productID("MICROSD");
  usbMsc.productRevision("1.0");

  usbMsc.onRead(myMscRead);
  usbMsc.onWrite(myMscWrite);
  usbMsc.onStartStop(myMscStartStop);
  usbMsc.mediaPresent(true);

  USB.begin();
  if (!usbMsc.begin(sectorCount, SECTOR_SIZE)) {
    Serial.println("usbMsc.begin() FAILED");
  } else {
    Serial.println("MSC READY : la carte doit apparaître comme un disque USB.");
  }

}




// SETUP (simplifié)
// =======================
void setup() {
  Serial.begin(115200);
  delay(500);
  Serial.println("\n=== WAV Player ESP32-S3 + MAX99357 ===");

    // Si le bouton est appuyé au boot → mode MSC
  if (digitalRead(BTN_PIN) == HIGH) {
    Serial.println("Mode MSC (clé USB)");
    setupMassStorageMode();
  } 
  else {
    Serial.println("Mode Audio (lecteur WAV)");
    setupAudioMode();
  }

  pinMode(AMP_SD_MODE_PIN, OUTPUT);
  digitalWrite(AMP_SD_MODE_PIN, LOW);
}

void loop() {

  vTaskDelay(10000);
}


// =======================
// Task de playback avec queue
// =======================
void playbackTask(void *parameter) {
  (void)parameter;

  for (;;) {
    if (g_wavCmdQueue == NULL) {
      vTaskDelay(pdMS_TO_TICKS(100));
      continue;
    }

    WavCommand cmd;
    // On attend une commande
    if (xQueueReceive(g_wavCmdQueue, &cmd, portMAX_DELAY) == pdTRUE) {

      if (cmd.cmd == 'p') {
        Serial.print("CMD PLAY: ");
        Serial.println(cmd.path);
        playWav(cmd.path, false);
      }
      else if (cmd.cmd == 'l') {
        Serial.print("CMD LOOP: ");
        Serial.println(cmd.path);
        playWav(cmd.path, true);
      }
      else if (cmd.cmd == 's') {
        Serial.println("CMD STOP en idle (ignorée ici).");
      }
    }
  }
}

void buttonTask(void *parameter) {
  (void)parameter;

  uint16_t wav_index = 0;

  bool pressed       = false;
  uint32_t pressTime = 0;

  bool isplaying=false;
  WavCommand cmd;

  pinMode(BTN_PIN, INPUT_PULLDOWN);

  for (;;) {

    // Si pas de queue ou pas de fichier, on ne fait rien
    if (g_wavCmdQueue == nullptr || wavList.empty()) {
      vTaskDelay(pdMS_TO_TICKS(50));
      continue;
    }

    int state = digitalRead(BTN_PIN);
    uint32_t now = millis();

    // --- Front HAUT -> BAS = début d'appui ---
    if (!pressed && state == HIGH) {
      pressed   = true;
      pressTime = now;
    }

    // --- Front BAS -> HAUT = relâchement ---
    if (pressed && state == LOW) {
      pressed = false;
      uint32_t duration = now - pressTime;

      if (duration >= LONG_PRESS_MS) {
        Serial.println(">>> APPUI LONG détecté <<<");

        wav_index = (wav_index + 1);
        if (wav_index >= wavList.size()) {
          wav_index = 0;
        }
        cmd.cmd = 's';
        xQueueSend(g_wavCmdQueue, &cmd, 0);
        cmd.cmd = 'p';
        String fullPath = "/" + wavList[wav_index];
        strncpy(cmd.path, fullPath.c_str(), sizeof(cmd.path));
        cmd.path[sizeof(cmd.path) - 1] = '\0';
        xQueueSend(g_wavCmdQueue, &cmd, 0);

      } 
      else {
        Serial.println(">>> APPUI COURT détecté <<<");

        if(isplaying){
        isplaying = false;
        cmd.cmd = 's';
        xQueueSend(g_wavCmdQueue, &cmd, 0);
        }
        else{
        isplaying = true;
        cmd.cmd = 'p';
        String fullPath = "/" + wavList[wav_index];
        strncpy(cmd.path, fullPath.c_str(), sizeof(cmd.path));
        cmd.path[sizeof(cmd.path) - 1] = '\0';
        xQueueSend(g_wavCmdQueue, &cmd, 0);
        }
      }
    }
    vTaskDelay(pdMS_TO_TICKS(10));  // scan 100 Hz
  }
}

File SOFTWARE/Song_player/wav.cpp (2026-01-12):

#include <Arduino.h>
#include "wav.h"
#include "driver/i2s.h"   // <-- indispensable pour i2s_config_t, etc.
#include <SD.h>

QueueHandle_t g_wavCmdQueue = NULL;   // sera créé dans le .ino

const uint32_t LOOP_DELAY_MS = 500;


// =======================
// Appliquer volume logiciel
// =======================
int16_t applyVolume(int16_t sample) {
  // Volume logiciel simple : float -> int16
  float s = (float)sample * g_volume;

  // Saturation pour éviter overflow
  if (s > 32767.0f) s = 32767.0f;
  if (s < -32768.0f) s = -32768.0f;

  return (int16_t)s;
}
// =======================
// Init I2S pour MAX99357
// =======================
bool initI2S(uint32_t sampleRate) {
  static bool i2sAlreadyInit = false;

  i2s_config_t i2s_config = {
    .mode = (i2s_mode_t)(I2S_MODE_MASTER | I2S_MODE_TX),
    .sample_rate = sampleRate,
    .bits_per_sample = I2S_BITS_PER_SAMPLE_16BIT,
    .channel_format = I2S_CHANNEL_FMT_RIGHT_LEFT,
    .communication_format = I2S_COMM_FORMAT_STAND_I2S,
    .intr_alloc_flags = ESP_INTR_FLAG_LEVEL1,
    .dma_buf_count = 8,
    .dma_buf_len = 256,
    .use_apll = false,
    .tx_desc_auto_clear = true,
    .fixed_mclk = 0
  };

  i2s_pin_config_t pin_config = {
    .bck_io_num = I2S_BCLK_PIN,
    .ws_io_num = I2S_LRCLK_PIN,
    .data_out_num = I2S_DOUT_PIN,
    .data_in_num = I2S_PIN_NO_CHANGE
  };

  if (!i2sAlreadyInit) {
    if (i2s_driver_install(I2S_NUM_0, &i2s_config, 0, NULL) != ESP_OK) {
      Serial.println("i2s_driver_install failed");
      return false;
    }
    if (i2s_set_pin(I2S_NUM_0, &pin_config) != ESP_OK) {
      Serial.println("i2s_set_pin failed");
      return false;
    }
    i2sAlreadyInit = true;
  }

  if (i2s_set_sample_rates(I2S_NUM_0, sampleRate) != ESP_OK) {
    Serial.println("i2s_set_sample_rates failed");
    return false;
  }

  return true;
}

// =======================
// Lecture du header WAV
// =======================
bool readWavHeader(File &f, WavHeader &hdr) {
  // Repartir du début du fichier
  f.seek(0);

  char riff[4];
  char wave[4];
  uint32_t riffSize;

  // Lire "RIFF"
  if (f.read((uint8_t *)riff, 4) != 4) return false;
  if (f.read((uint8_t *)&riffSize, 4) != 4) return false;
  if (f.read((uint8_t *)wave, 4) != 4) return false;

  if (strncmp(riff, "RIFF", 4) != 0) return false;
  if (strncmp(wave, "WAVE", 4) != 0) return false;

  bool fmtFound  = false;
  bool dataFound = false;

  // Parcourt les sous-chunks jusqu'à trouver "fmt " et "data"
  while (f.available()) {
    char  subId[4];
    uint32_t subSize;

    // Lire ID du chunk (4 octets) + taille (4 octets)
    if (f.read((uint8_t *)subId, 4) != 4) return false;
    if (f.read((uint8_t *)&subSize, 4) != 4) return false;

    // ---- Chunk "fmt " ----
    if (strncmp(subId, "fmt ", 4) == 0) {
      if (subSize < 16) {
        // Chunk fmt trop petit → pas un WAV PCM standard
        return false;
      }

      uint8_t fmtBuf[16];
      if (f.read(fmtBuf, 16) != 16) return false;

      // Tout est little-endian
      hdr.audioFormat   = (uint16_t)(fmtBuf[0] | (fmtBuf[1] << 8));
      hdr.channels      = (uint16_t)(fmtBuf[2] | (fmtBuf[3] << 8));
      hdr.sampleRate    = (uint32_t)(fmtBuf[4] |
                                     (fmtBuf[5] << 8) |
                                     (fmtBuf[6] << 16) |
                                     (fmtBuf[7] << 24));
      // byteRate = fmtBuf[8..11] (pas forcément utilisé)
      // blockAlign = fmtBuf[12..13]
      hdr.bitsPerSample = (uint16_t)(fmtBuf[14] | (fmtBuf[15] << 8));

      // Si le chunk fmt est plus grand que 16 octets → on saute le reste
      if (subSize > 16) {
        uint32_t toSkip = subSize - 16;
        f.seek(f.position() + toSkip);
      }

      fmtFound = true;
    }
    // ---- Chunk "data" ----
    else if (strncmp(subId, "data", 4) == 0) {
      hdr.dataSize = subSize;
      dataFound = true;
      // On s'arrête ici : le prochain octet à lire = début des samples PCM
      break;
    }
    // ---- Chunk inconnu → on saute ----
    else {
      // On saute la taille indiquée
      f.seek(f.position() + subSize);
    }
  }

  if (!fmtFound || !dataFound) {
    return false;
  }

  // On vérifie juste que c'est bien du PCM classique, le reste sera filtré dans le code appelant
  if (hdr.audioFormat != 1) {
    // 1 = PCM non compressé
    Serial.print("Format audio non PCM, code = ");
    Serial.println(hdr.audioFormat);
    return false;
  }

  return true;
}

// =======================
// Fonction bloquante playWav
// =======================
void playWav(const char *path, bool loop) {
  bool stopRequested = false;

  do {
    File wavFile = SD.open(path);
    if (!wavFile) {
      Serial.print("Impossible d'ouvrir : ");
      Serial.println(path);
      return;  // on sort, la tâche décidera quoi faire
    }

    WavHeader hdr;
    if (!readWavHeader(wavFile, hdr)) {
      Serial.println("Header WAV invalide / non supporté.");
      wavFile.close();
      return;
    }

    if (hdr.bitsPerSample != 16) {
      Serial.println("Seulement 16 bits supportés.");
      wavFile.close();
      return;
    }

    if (hdr.channels != 1 && hdr.channels != 2) {
      Serial.println("Seulement mono ou stéréo supportés.");
      wavFile.close();
      return;
    }

    if (!initI2S(hdr.sampleRate)) {
      Serial.println("Erreur init I2S.");
      wavFile.close();
      return;
    }

    // Activer l'ampli juste avant de jouer
    digitalWrite(AMP_SD_MODE_PIN, HIGH);
    vTaskDelay(pdMS_TO_TICKS(5));

    const size_t BUF_SIZE = 1024;
    uint8_t buf[BUF_SIZE];

    Serial.print("Lecture du WAV : ");
    Serial.println(path);

    size_t bytesRead;
    while ((bytesRead = wavFile.read(buf, BUF_SIZE)) > 0) {

      // 🔸 Check éventuel STOP venant de la queue
      if (g_wavCmdQueue != NULL) {
        WavCommand cmd;
        if (xQueueReceive(g_wavCmdQueue, &cmd, 0) == pdTRUE) {
          if (cmd.cmd == 's') {
            Serial.println("Commande STOP reçue.");
            stopRequested = true;
            // on ne traite pas ici d'autres cmd (p/l) → à ajouter si besoin
          }
        }
      }

      if (stopRequested) break;

      if (hdr.channels == 1) {
        // MONO 16 bits -> stéréo + volume
        size_t samplesMono = bytesRead / 2;
        static int16_t tempStereo[BUF_SIZE]; // 1024 int16 -> 2048 bytes max utilisé

        size_t stereoCount = 0;
        int16_t *src = (int16_t *)buf;

        for (size_t i = 0; i < samplesMono; i++) {
          int16_t s = applyVolume(src[i]);
          tempStereo[stereoCount++] = s;
          tempStereo[stereoCount++] = s;
        }

        size_t bytesToWrite = stereoCount * 2;
        size_t written = 0;
        while (written < bytesToWrite) {
          size_t w = 0;
          i2s_write(I2S_NUM_0,
                    ((uint8_t *)tempStereo) + written,
                    bytesToWrite - written,
                    &w,
                    portMAX_DELAY);
          written += w;
        }
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

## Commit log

2026-01-12 Add README with project specifications and features
    Added detailed hardware and software specifications for the LABUBU IA project, including components, PCB details, images, and functionality of the audio player and AI assistant.
2026-01-12 Update README with 3D PCB case images
    Added images for 3D PCB case and updated layout.
2026-01-12 Update README with PCB images and descriptions
    Added images and descriptions of PCB and components.

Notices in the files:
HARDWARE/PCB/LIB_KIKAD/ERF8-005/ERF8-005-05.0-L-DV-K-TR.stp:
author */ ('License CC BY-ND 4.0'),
